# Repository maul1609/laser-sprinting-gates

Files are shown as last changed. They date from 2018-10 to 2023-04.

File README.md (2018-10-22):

# Laser Sprinting Gates

This Laser Sprinting Gate (LSG) project uses two Arduino Nanos and an Arduino Uno linked together via 
nRF24l01 modules. 

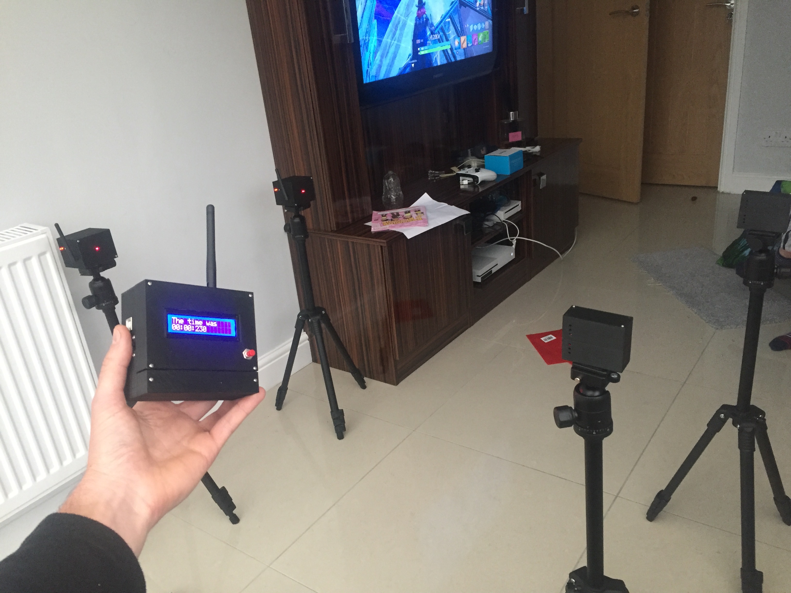
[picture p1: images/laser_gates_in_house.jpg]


<em>The Laser Speed Gates - Indoors.</em>

# Table of contents
1. [Overview](#overview)
2. [Remote control](#rem-cont)
3. [Detectors](#detectors)
4. [Dependencies](#Dependencies)
5. [Folder structure](#Folder-Structure)
6. [Contributing](#Contributing)
7. [Code of Conduct](#Code-of-Conduct)

## Overview 

The electronics fits in their own project boxes, which are 3-d printed.

There are two boxes for the laser diodes, two for the detectors / transceivers; and one for the remote control.

You set up the tripods, point the lasers into the detectors a measured distance apart and switch everything on.

Then press the pushbutton on the remote control. The LCD will say "Ready" if the laser gates are closed, or will tell you to "Close gates" if the lasers are not directed on the photodiodes.

When you run through both gates the remote control will display your time on the LCD in <b>min:sec:ms</b> format.

## Remote Control 
The remote control is operated as a "master" to two "slaves" (the detectors). When the reset button is pressed a signal is sent to the two slaves, which send a return packet using the AckPayload protocol. The signal from the master includes the time in milli-seconds when the signal is sent (which is the reference time).

The information in the return packet includes information on whether the gates are closed (i.e. laser pointing at the photodiode); the reference time; and the time at which the gate was first opened (laser beam broken) after the reset signal. If both gates have been opened the difference between these two times is the time taken. This time is then printed to the remote control LCD.

The LCD uses the LiquidCrystal library and the following code to interface to it:

<code>
LiquidCrystal lcd(1,0,5,4,3,2);
</code>

However, this may change so that the master uses pin 2 or 3 for the reset button (as an interupt can then be attached).

The remote control enclosure is 3-D printed (designs are part of this repository).

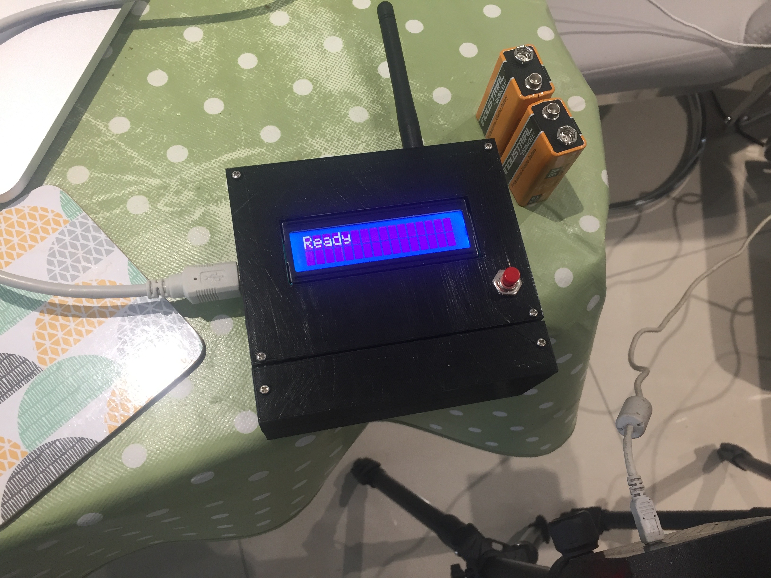
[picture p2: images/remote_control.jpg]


<em>The remote control consists of an Arduino Uno; nRF24L01 transceiver module; reset button; and LCD screen.</em>

Upload the master.ino to the arduino UNO.

## Detectors 
The detectors both use an Arduino Nano; nRF24L01 modules. The pins used on the Nano (same for the Uno board used in the remote control) are:

<table style="width:100%">
  <tr> 
    <td>
    Arduino Pin <br>
    </td>
    <td>
    nRF24L01 Pin
    </td>
  </tr>
  <tr> 
    <td>
    3.3V <br>
    </td>
    <td>
    VCC
    </td>
  </tr>
  <tr> 
    <td>
    GND <br>
    </td>
    <td>
    GND
    </td>
  </tr>
  <tr> 
    <td>
    8 <br>
    </td>
    <td>
    CSN
    </td>
  </tr>
  <tr> 
    <td>
    7 <br>
    </td>
    <td>
    CE
    </td>
  </tr>
  <tr> 
    <td>
    13 <br>
    </td>
    <td>
    SCK
    </td>
  </tr>
  <tr> 
    <td>
    11 <br>
    </td>
    <td>
    MOSI
    </td>
  </tr>
  <tr> 
    <td>
    12 <br>
    </td>
    <td>
    MISO
    </td>
  </tr>
</table>

There is also an interface to a photodiode circuit (a photodiode, two resistors and a p-type transistor), which goes to pin 2.

The photodiode circuit used is taken from Figure 3, using circuit A, with RBE=1 kohm, RL=10 kohm and a BD140 (p-type) transistor [see here](reference/Photodiode_circuit.pdf).

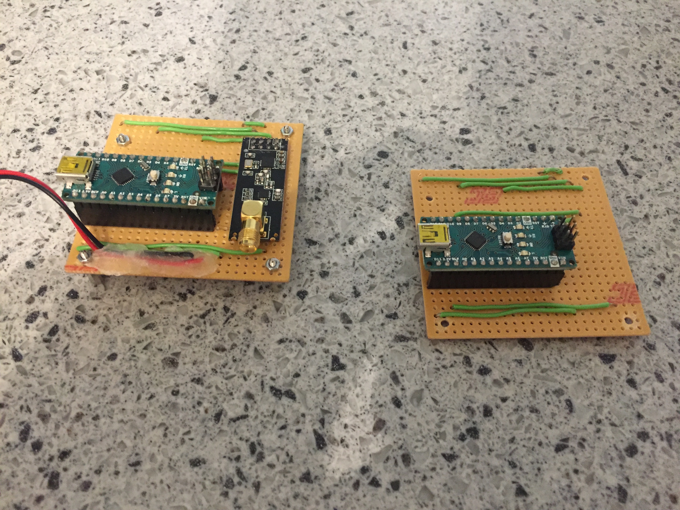
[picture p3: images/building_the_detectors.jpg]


<em>Two detector boards being constructed.</em>

Upload the slaves.ino to the Arduino Nanos: one should have 

<code>thisSlaveAddress set to RxAAA</code> 

and the other

<code>thisSlaveAddress set to RxAAB</code> 

(change the address on approximate line 12 / 13 or the slaves.ino file).

## Dependencies 

I needed to install two libraries for the Arduino for communication. The libraries are nRF24L01 and RF24.

## Folder structure 

The repository structure is now discussed

### Directory layout

    .                           
    ├── arduino               # code for the Arduino
    ├── images                # image files for the project
    ├── links                 # some links that I used 
    ├── openSCAD              # Design files in openSCAD
    ├── README.md             # This readme
    └── reference			  # contains reference documents
    
----------

**REQUIRED PARTS**

In order to **make your own Laser Sprinting Gates**, you may use the **part list below** to acquire all the components **on your own**.

<table style="width:100%">
  <tr>
    <td>
    Arduino Uno <br>
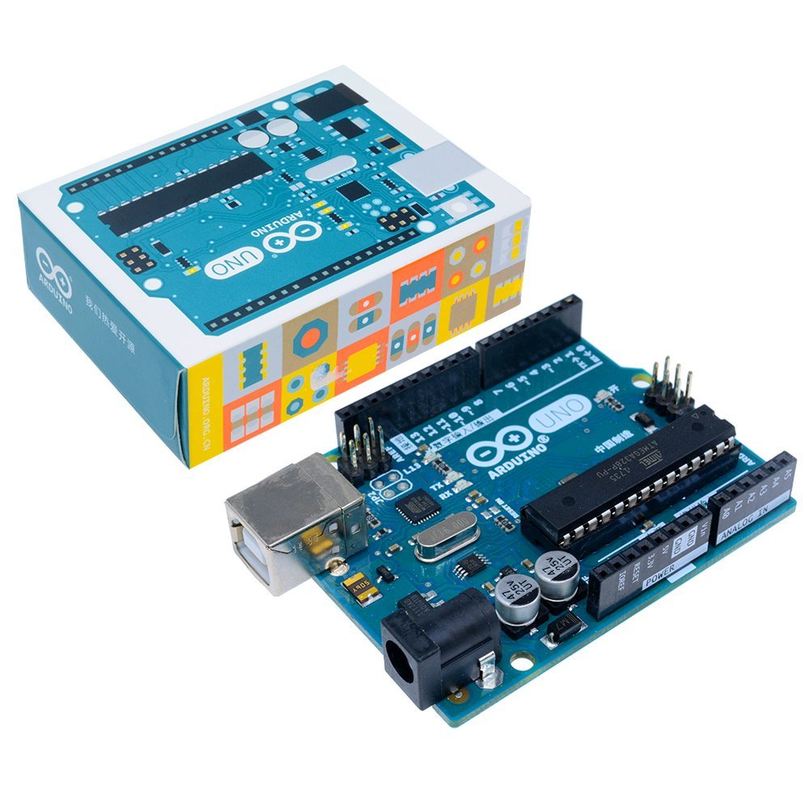
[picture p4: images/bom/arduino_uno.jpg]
    </td>
    <td><a href="https://www.amazon.co.uk/Arduino-ATMega16U2-ATMEGA328P-Microcontroller-Official/dp/B077JMX1NP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" target="_blank"> Amazon </a></td> 
    <td>£20</td>
  </tr>

  <tr>
    <td>
    Arduino Nano A000005 Board V3 x2<br>
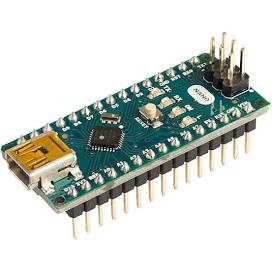
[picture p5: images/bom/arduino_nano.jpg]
    </td>
    <td><a href="https://www.rapidonline.com/arduino-nano-a000005-board-v3-73-4448" target="_blank"> Rapid Electronics </a></td> 
    <td>£15.60 x 2 = £31.20</td>
  </tr>

  <tr>
    <td>
    Strip board <br>
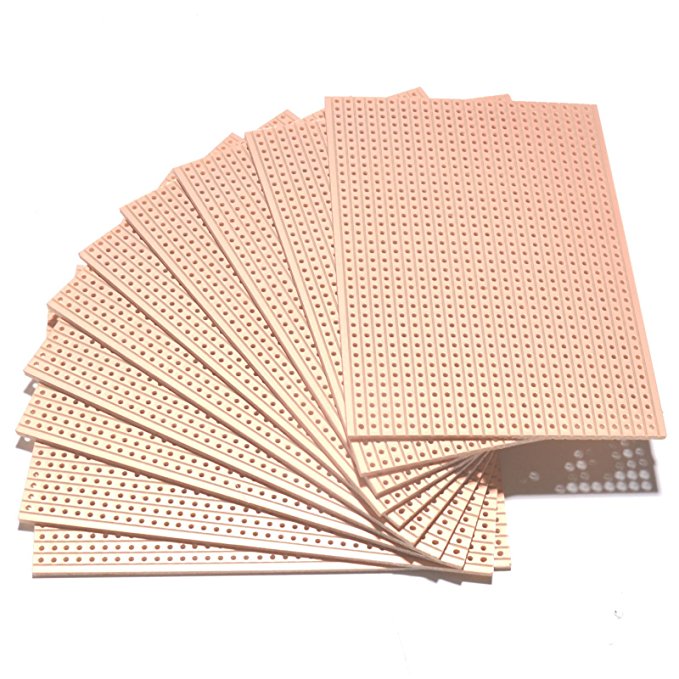
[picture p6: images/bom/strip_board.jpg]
    </td>
    <td><a href="https://www.amazon.co.uk/gp/product/B072PS947V/ref=oh_aui_detailpage_o09_s00?ie=UTF8&psc=1" target="_blank"> Amazon </a></td> 
    <td>£10</td>
  </tr>

  <tr>
    <td>
    Slide switch <br>
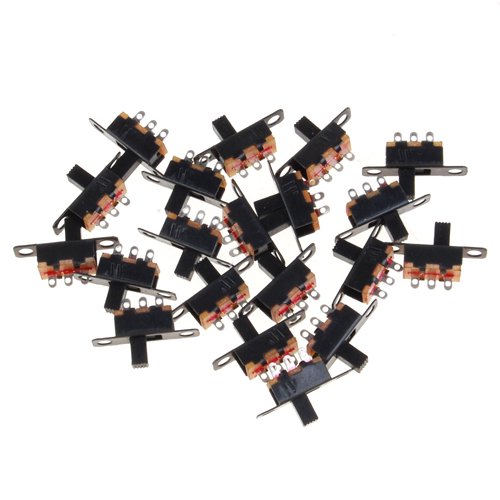
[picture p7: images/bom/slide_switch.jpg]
    </td>
    <td><a href="https://www.amazon.co.uk/gp/product/B008R50AA0/ref=oh_aui_detailpage_o07_s00?ie=UTF8&psc=1" target="_blank"> Amazon </a></td> 
    <td>£0.15</td>
  </tr>
  
  <tr>
    <td>
    PCB Header Connectors <br>
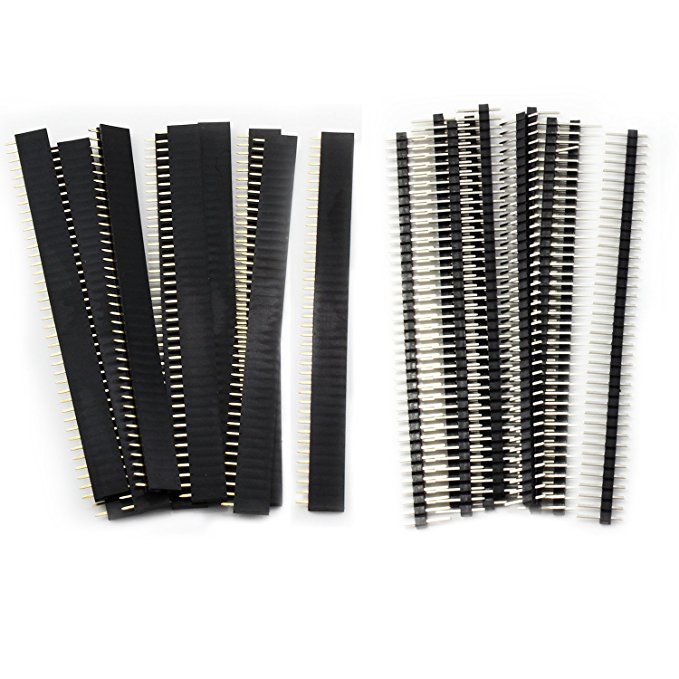
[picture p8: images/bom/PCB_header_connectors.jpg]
    </td>
    <td><a href="https://www.amazon.co.uk/gp/product/B01M69EA9O/ref=oh_aui_detailpage_o03_s00?ie=UTF8&psc=1" target="_blank"> Amazon </a></td> 
    <td>£5</td>
  </tr>

  <tr>
    <td>
    Affix Pozi Pan Head Stainless Steel Screws M2.5 12mm  <br>
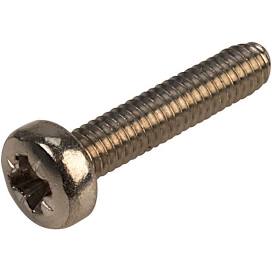
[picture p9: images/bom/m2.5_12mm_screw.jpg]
    </td>
    <td><a href="https://www.rapidonline.com/Affix-Pozi-Pan-Head-Stainless-Steel-Screws-M2-5-12mm-Pack-Of-100-33-4205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" target="_blank"> Rapid online </a></td> 
    <td>£3.40</td>
  </tr>
  
  <tr>
    <td>
    Affix Stainless Steel Plain Washers M2.5  <br>
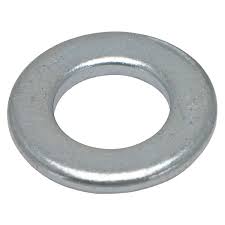
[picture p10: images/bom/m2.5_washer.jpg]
    </td>
    <td><a href="https://www.rapidonline.com/affix-stainless-steel-plain-washers-m2-5-pack-of-100-33-4315" target="_blank"> Rapid online </a></td> 
    <td>£1</td>
  </tr>
  
  <tr>
    <td>
    M2.5 nuts <br>
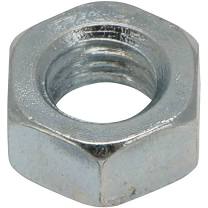
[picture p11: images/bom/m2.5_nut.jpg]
    </td>
    <td><a href="https://www.rapidonline.com/tr-fastenings-w-m2-5-hfst-tc1-steel-full-nuts-metric-m2-5-box-of-100-33-6589" target="_blank"> Rapid online </a></td> 
    <td>£1.20</td>
  </tr>

  <tr>
    <td>
    10 Metres 4mm Brown Sleeving On A Roll. <br>
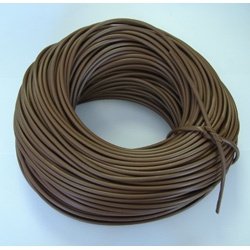
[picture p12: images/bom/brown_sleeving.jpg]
    </td>
    <td><a href="https://www.amazon.co.uk/gp/product/B006I1K7NU/ref=oh_aui_search_detailpage?ie=UTF8&psc=1" target="_blank"> Amazon </a></td> 
    <td>£2.99</td>
  </tr>
  
  <tr>
    <td>
    LED <br>
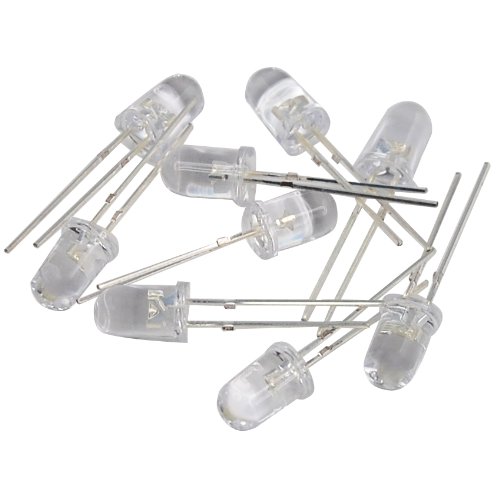
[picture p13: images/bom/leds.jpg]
    </td>
    <td><a href="https://www.amazon.co.uk/dp/B00CM5DEZO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" target="_blank"> Amazon </a></td> 
    <td>£0.65</td>
  </tr>

  <tr>
    <td>
    Linear regulator <br>
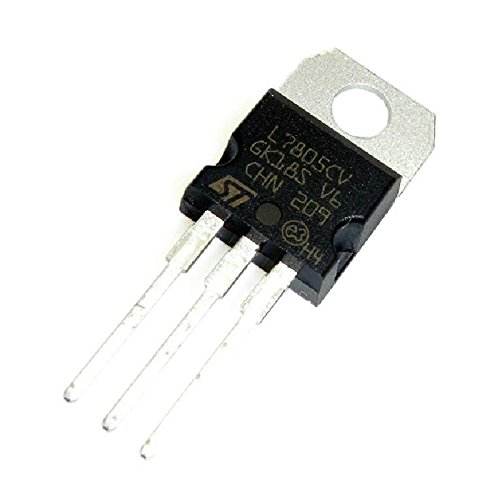
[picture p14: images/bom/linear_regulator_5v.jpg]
    </td>
    <td><a href="https://www.amazon.co.uk/LM338T-Adjustable-Positive-Voltage-Regulator/dp/B07F2YMXTR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" target="_blank"> Amazon </a></td> 
    <td>£3</td>
  </tr>

  <tr>
    <td>
    nRF24L01 module <br>
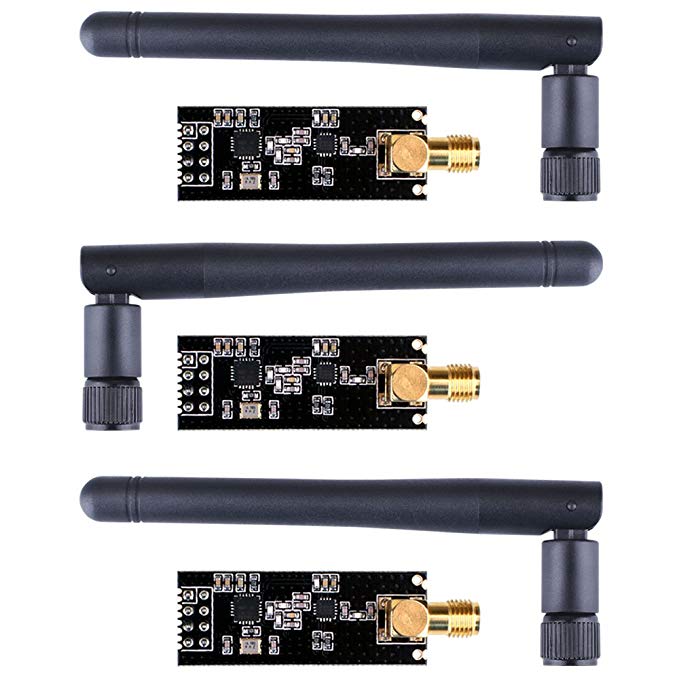
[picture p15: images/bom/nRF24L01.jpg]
    </td>
    <td><a href="https://www.amazon.co.uk/gp/product/B06WD17WLS/ref=oh_aui_detailpage_o08_s00?ie=UTF8&psc=1"> Amazon </a></td> 
    <td>£13.99</td>
  </tr>

  <tr>
    <td>
    photodiodes <br>
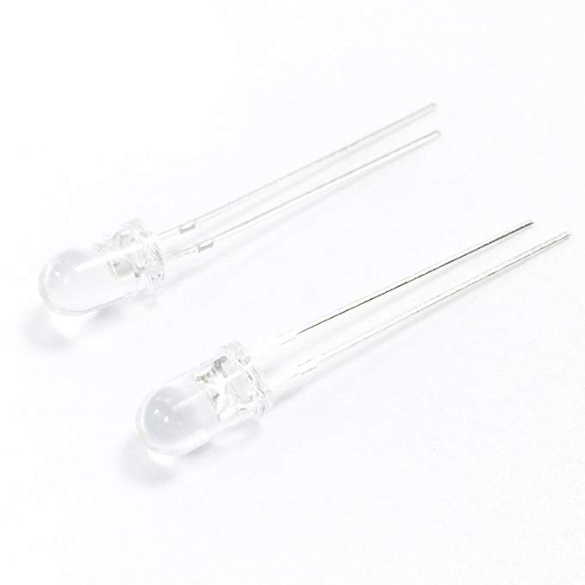
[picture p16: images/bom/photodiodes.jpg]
    </td>
    <td><a href="https://www.amazon.co.uk/gp/product/B00M1PMHO4/ref=oh_aui_detailpage_o08_s01?ie=UTF8&psc=1"> Amazon </a></td> 
    <td>£2.99</td>
  </tr>
  
  <tr>
    <td>
    Laser diodes <br>
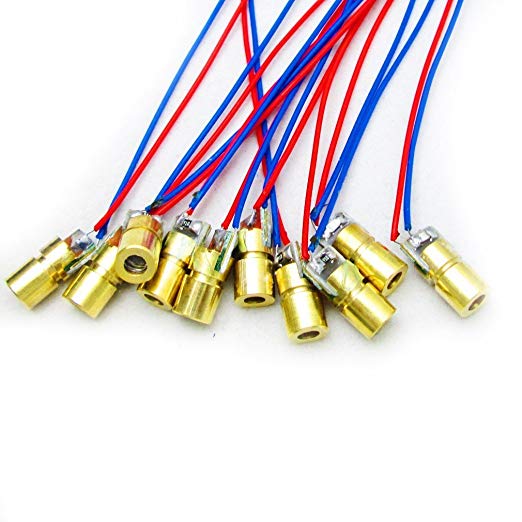
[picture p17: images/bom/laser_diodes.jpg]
    </td>
    <td><a href="https://www.amazon.co.uk/gp/product/B0798PXGTS/ref=oh_aui_detailpage_o08_s02?ie=UTF8&psc=1"> Amazon </a></td> 
    <td>£3.99</td>
  </tr>

  <tr>
    <td>
    LCD <br>
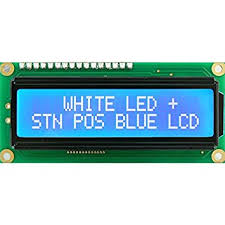
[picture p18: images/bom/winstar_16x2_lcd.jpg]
    </td>
    <td><a href="https://www.rapidonline.com/winstar-wh1602b-tmi-jt-16x2-lcd-display-blue-negative-mode-white-led-backlight-57-2228"> Rapid electronics </a></td> 
    <td>£6.40</td>
  </tr>

  <tr>
    <td>
    Pushbutton switch <br>
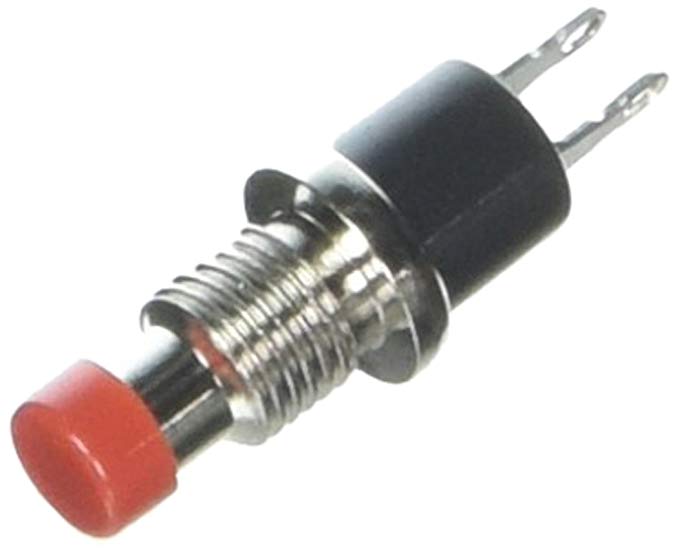
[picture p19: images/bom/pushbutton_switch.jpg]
    </td>
    <td><a href="https://www.amazon.co.uk/gp/product/B00KHV7QFE/ref=oh_aui_detailpage_o01_s00?ie=UTF8&psc=1" target="_blank"> Amazon </a></td> 
    <td>£2.22</td>
  </tr>
	
  <tr>
    <td>
    9V battery clip connector <br>
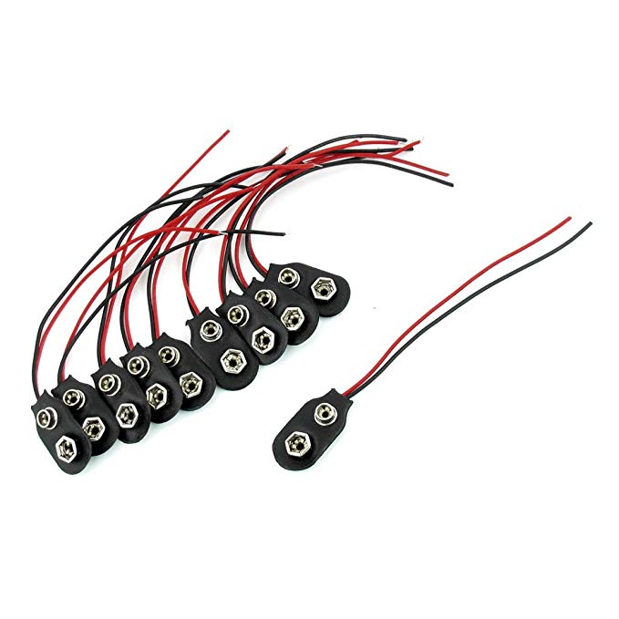
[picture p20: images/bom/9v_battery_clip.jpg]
    </td>
    <td><a href="https://www.amazon.co.uk/gp/product/B00HG8BJWM/ref=oh_aui_search_detailpage?ie=UTF8&psc=1" target="_blank"> Amazon </a></td> 
    <td>£0.87</td>
  </tr>
	
  <tr>
    <td>
    M2x50mm screws (cut to size) <br>
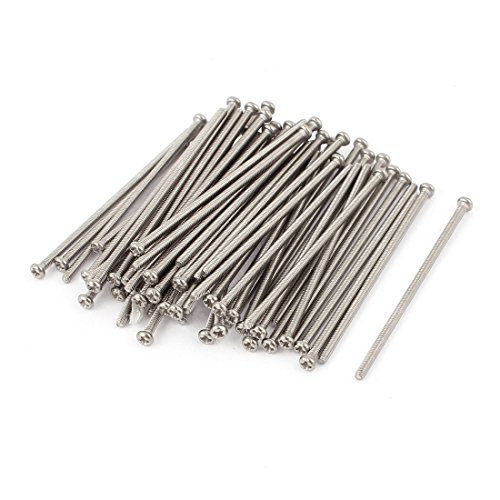
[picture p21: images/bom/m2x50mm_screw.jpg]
    </td>
    <td><a href="https://www.amazon.co.uk/Stainless-Steel-Phillips-Round-Screws/dp/B01EZZFBDG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" target="_blank"> Amazon </a></td> 
    <td>£14.35</td>
  </tr>
	
  <tr>
    <td>
    Tripod Socket <br>
    </td>
    <td><a href="https://www.amazon.co.uk/Hillman-Group-2511-4-20-13-Pack/dp/B00HYLZ33W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"> Amazon </a></td> 
    <td>£10</td>
  </tr>
	
  <tr>
    <td>
    m2 counter sunk <br>
    </td>
    <td><a href="https://www.ettinger.de/en/product/0112138"> Ettinger or similar supplier </a></td> 
    <td>£3</td>
  </tr>
	
  <tr>
    <td>
    Hex Standoff Male/Female BSB-2010E, 10mm, M2 x M2 <br>
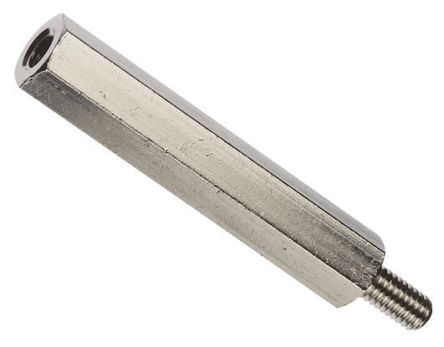
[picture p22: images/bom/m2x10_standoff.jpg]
    </td>
    <td><a href="https://uk.rs-online.com/web/p/standoffs/6643035/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"> RS </a></td> 
    <td>£7</td>
  </tr>

  <tr>
    <td>
    Hexagon Nut D934 M2 <br>
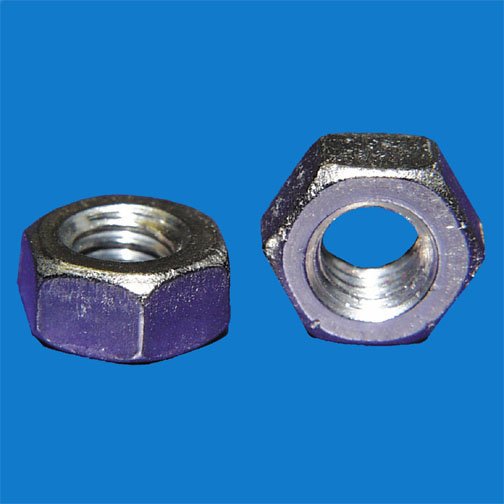
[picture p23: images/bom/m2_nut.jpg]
    </td>
    <td><a href="https://www.ettinger.de/en/product/0210011"> Ettinger or similar supplier </a></td> 
    <td>£2</td>
  </tr>
	
  <tr>
    <td>
    BD140 <br>
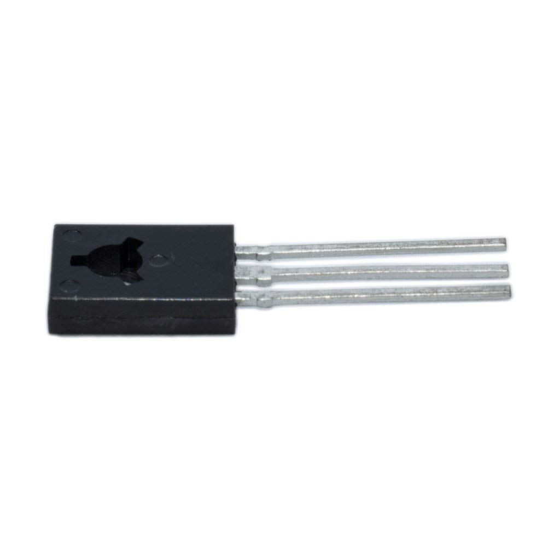
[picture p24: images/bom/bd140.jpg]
    </td>
    <td><a href="https://www.amazon.co.uk/BD140-10-CDI-Transistor-Bipolar-1-5A-TO126/dp/B07HR3BWLZ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"> Amazon </a></td> 
    <td>£3.50</td>
  </tr>

</table>

Plus: 
<ul>
<li> Resistors: 1k &Omega; ;2x220 &Omega; ;10 k &Omega;
<li> some other wire 22awg for low current connections;  
<li> Heat shrink for 22awg wire.
<li> 4 x 9V batteries
<li> 4x tripod stands. Good quality is obviously better, but you can get them quite cheap of ebay see <a href="https://www.ebay.co.uk/itm/Stretchable-Camera-Tripod-Stand-Mount-Holder-for-iPhone-8-7-Plus-Samsung-Phone/362434198720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"> here </a>
<li> 3-d printing materials:
	<ul>
	<li> PLA plastic
	</ul>
</ul>

## Contributing

Contributions to this Laser Sprinting Gate project are more than welcome. I am sure there are many improvements that could be made. I am very happy to discuss ideas for improvement and how to add/remove features.  

Please use the issue tracker at https://github.com/maul1609/laser-sprinting-gates/issues if you want to notify me of an issue or need support. If you want to contribute, please either create an issue or make a pull request. Alternatively, come and see me in Manchester and/or lets meet for a coffee and a chat!

## Code of Conduct

To be arranged.

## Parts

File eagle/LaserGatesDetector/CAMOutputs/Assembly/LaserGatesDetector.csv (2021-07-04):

Qty | Value | Device | Package | Parts | Description | PROD_ID | VALUE
1 | 0.1uF | 0.1UF-KIT-EZ-50V-20% | CAP-PTH-SMALL-KIT | C1 | 0.1µF ceramic capacitors | CAP-08370 | 0.1uF
1 | 100 | 100OHM-HORIZ-1/4W-1% | AXIAL-0.3 | R3 | 100Ω resistor | RES-12181 | 100
1 | 10K | 1MOHM-HORIZ-1/4W-5% | AXIAL-0.3 | R2 | 1MΩ resistor | RES-09329 | 1M
1 | 1K | 1MOHM-HORIZ-1/4W-5% | AXIAL-0.3 | R1 | 1MΩ resistor | RES-09329 | 1M
2 | 1k | 1KOHM-HORIZ-1/4W-1% | AXIAL-0.3 | R4, R5 | 1kΩ resistor | RES-12182 | 1k
1 | 1mF | 1000UF-RADIAL-5MM-25V-20% | CPOL-RADIAL-5MM-10MM | C3 | 1,000µF/1mF ceramic capacitors | CAP-09538 | 1mF
1 | 1uF | 10UF-POLAR-RADIAL-2.5MM-25V-20% | CPOL-RADIAL-2.5MM-5MM | C2 | 10.0µF polarized capacitors | CAP-08440 | 10uF
1 | BD140 | BD140 | TO126AV | Q1 | PNP TRANSISTOR
1 | NANO_FOOTPRINT | NANO_FOOTPRINT | NANO | J1 | Generic Nano Footprint
1 | NRF24L01 | NRF24L01 | NRF24L01 | U$1 | nrF54L01 2.4GHz with 100 Channels Emitter/Reveiver SPI Controlled
1 | PHOTOTRANSISTOR-SFH309 | PHOTOTRANSISTOR-SFH309 | SFH | U$2
1 | RED | LED5MM-KIT | LED_5MM-KIT | D1 | LED (Generic)
1 | SLIDE-SWITCH-CONRAD708070 | SLIDE-SWITCH-CONRAD708070 | SLIDE-SWITCH-CONRAD708070 | U$3
1 | VCC_1 | CONN_02 | 1X02 | J2 | Multi connection point. Often used as Generic Header-pin footprint for 0.1 inch spaced/style header connections
1 | V_REG_338T | V_REG_317SINK | TO220-ADJ | U1 | Voltage Regulator

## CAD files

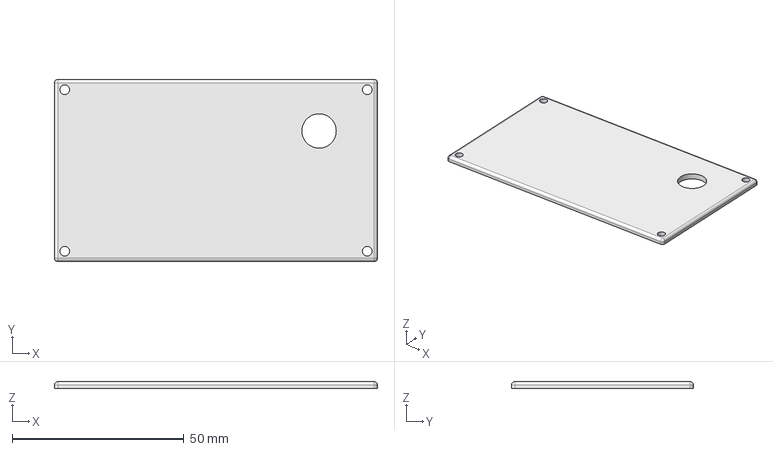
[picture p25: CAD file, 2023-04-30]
FreeCAD/receiver_lid.FCStd
94.0 x 53.0 x 2.00 mm

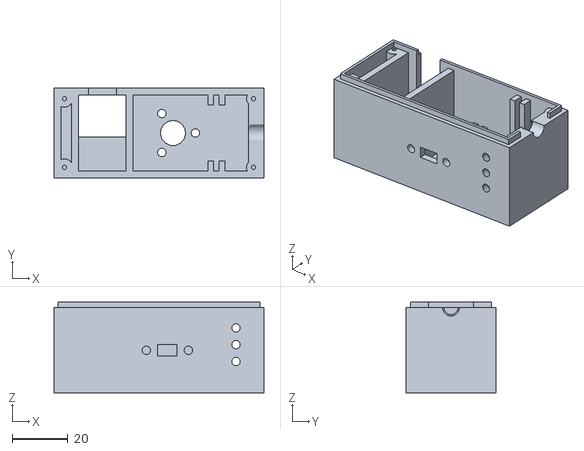
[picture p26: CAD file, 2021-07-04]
openSCAD/laser_box_bottom.stl
75.0 x 32.0 x 32.5

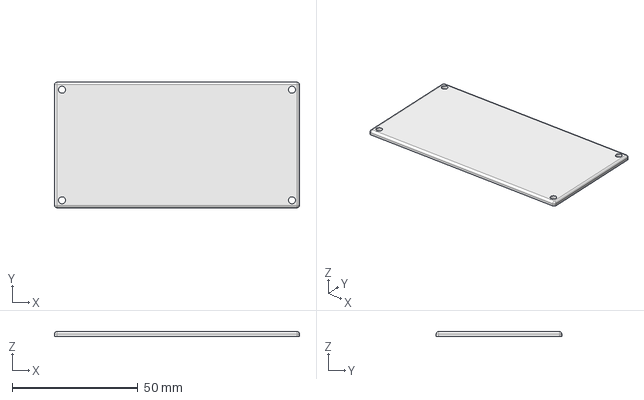
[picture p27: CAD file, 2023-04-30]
FreeCAD/remote_lid.FCStd
97.5 x 50.0 x 2.00 mm

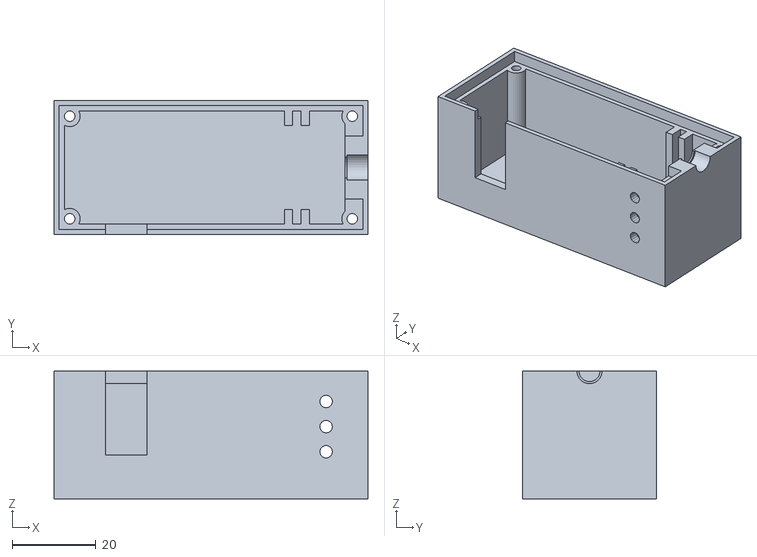
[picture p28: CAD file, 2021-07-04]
openSCAD/laser_box_top.stl
75.0 x 32.0 x 30.5

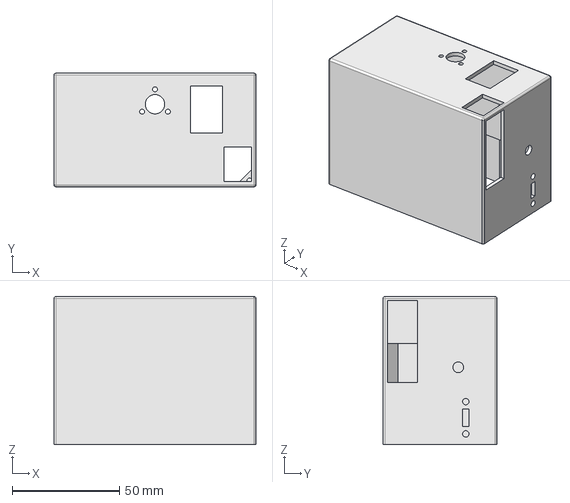
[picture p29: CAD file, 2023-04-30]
FreeCAD/receiver_box.FCStd
94.0 x 53.0 x 69.0 mm

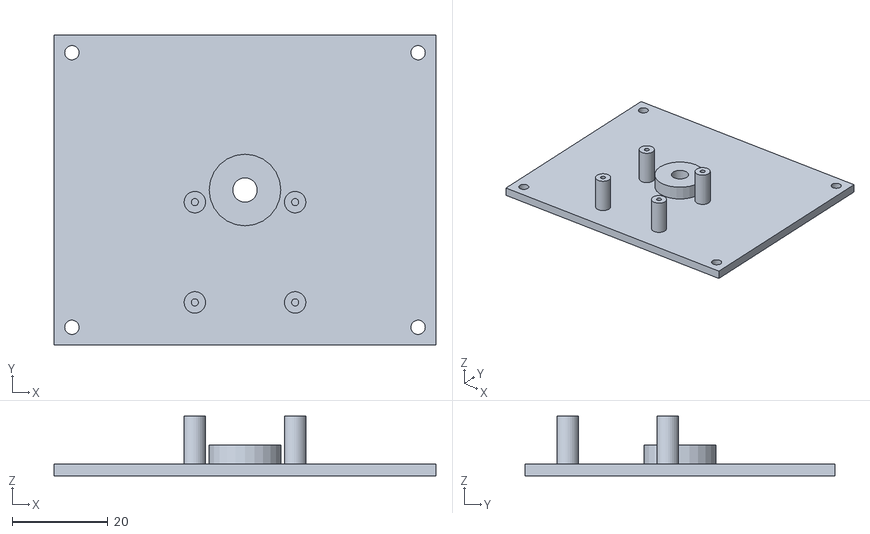
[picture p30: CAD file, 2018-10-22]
openSCAD/detector_cover.stl
80.0 x 65.0 x 12.5

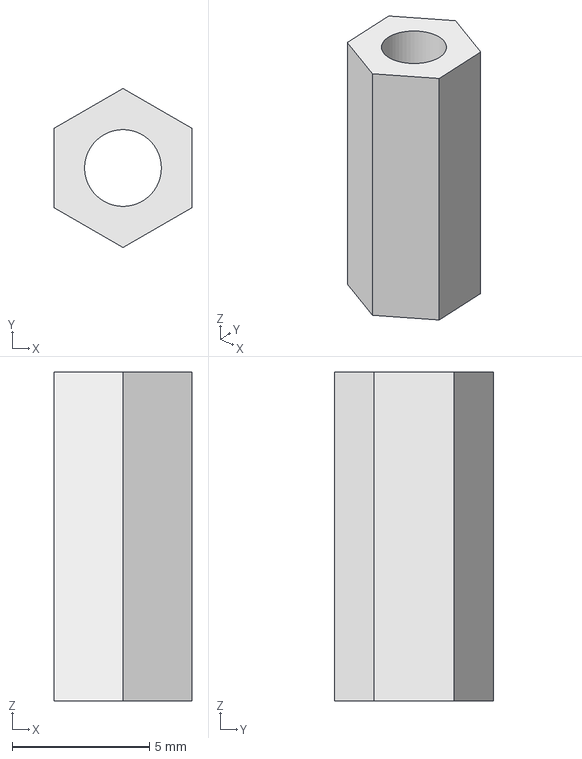
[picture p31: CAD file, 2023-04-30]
FreeCAD/LCD_spacer.FCStd
5.02 x 5.80 x 12.0 mm

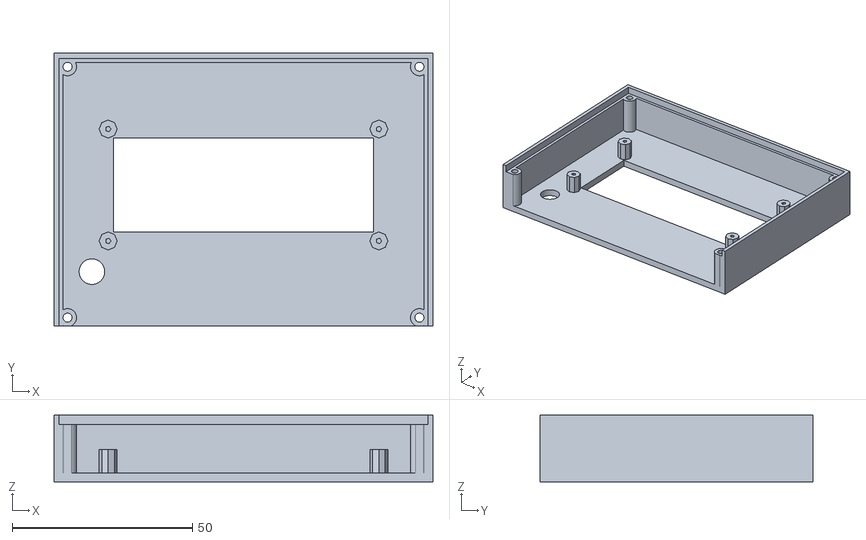
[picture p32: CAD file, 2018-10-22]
openSCAD/remote_controller_top_LCD_TOP.stl
105.0 x 75.5 x 18.5

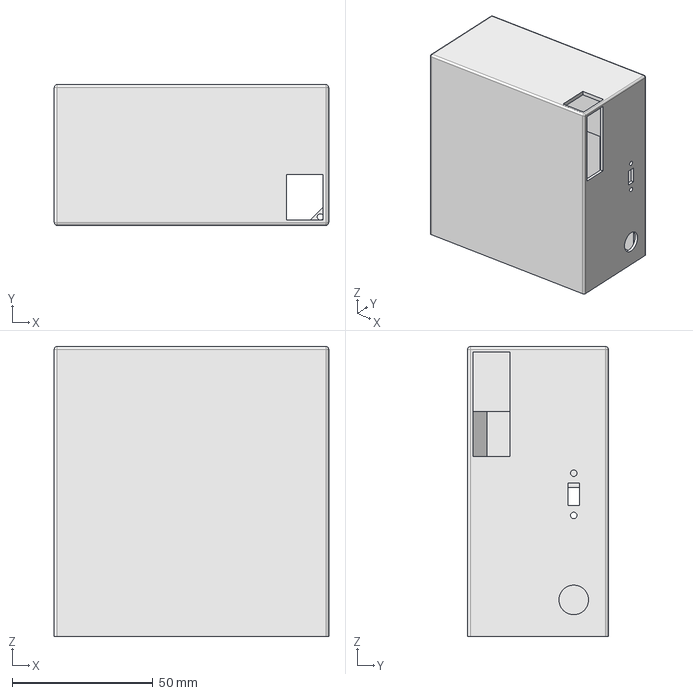
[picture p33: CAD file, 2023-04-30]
FreeCAD/remote_box.FCStd
97.5 x 50.0 x 103.0 mm

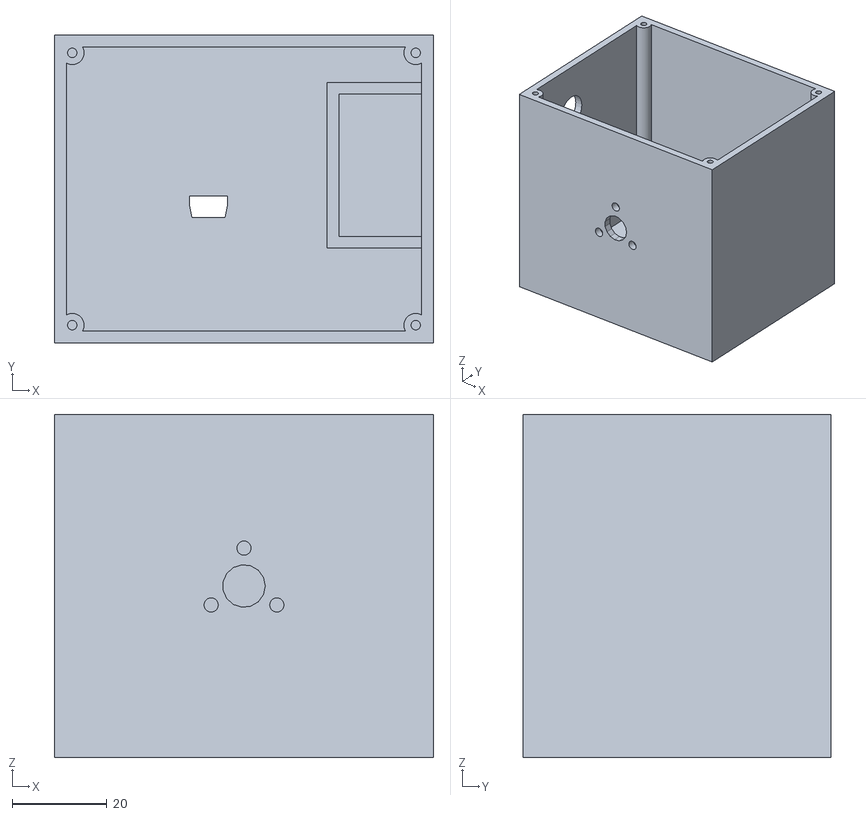
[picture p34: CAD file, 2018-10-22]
openSCAD/detector.stl
80.0 x 65.0 x 72.5

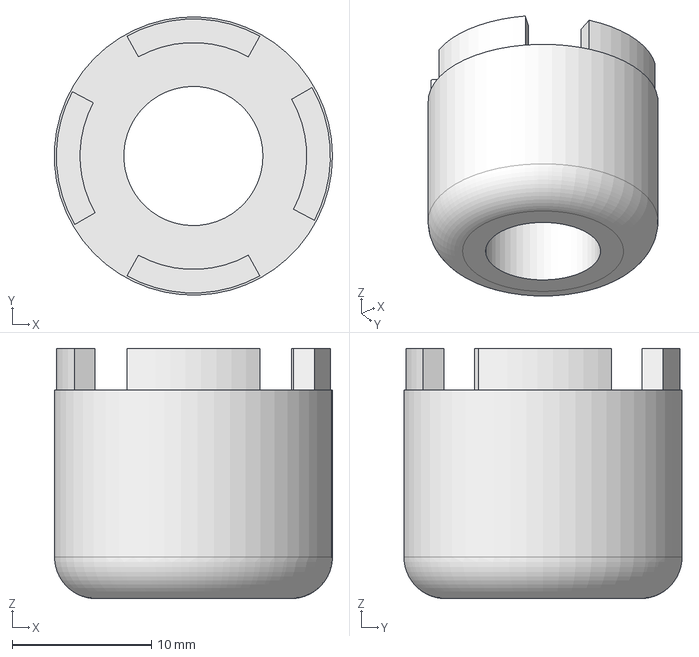
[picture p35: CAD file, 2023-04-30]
FreeCAD/remote_eye.FCStd
20.0 x 20.0 x 18.0 mm

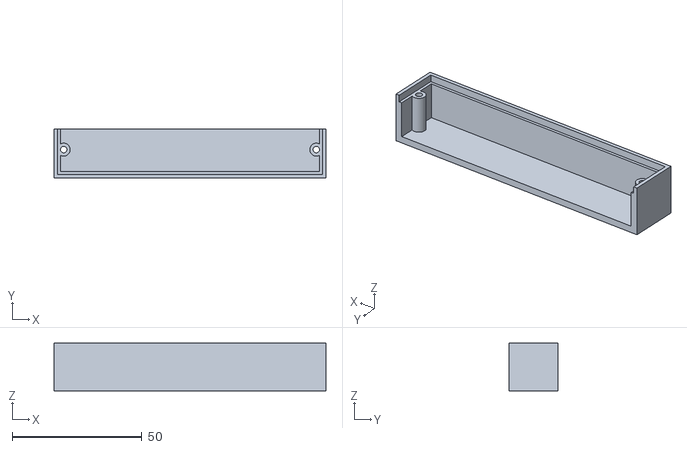
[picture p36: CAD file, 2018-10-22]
openSCAD/remote_controller_top_LCD_BOTTOM.stl
105.0 x 19.0 x 18.5

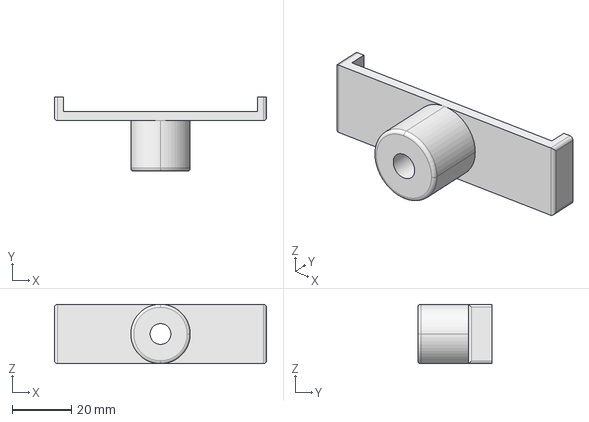
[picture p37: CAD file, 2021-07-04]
FreeCAD/sun_shield.FCStd
71.3 x 25.0 x 20.0 mm

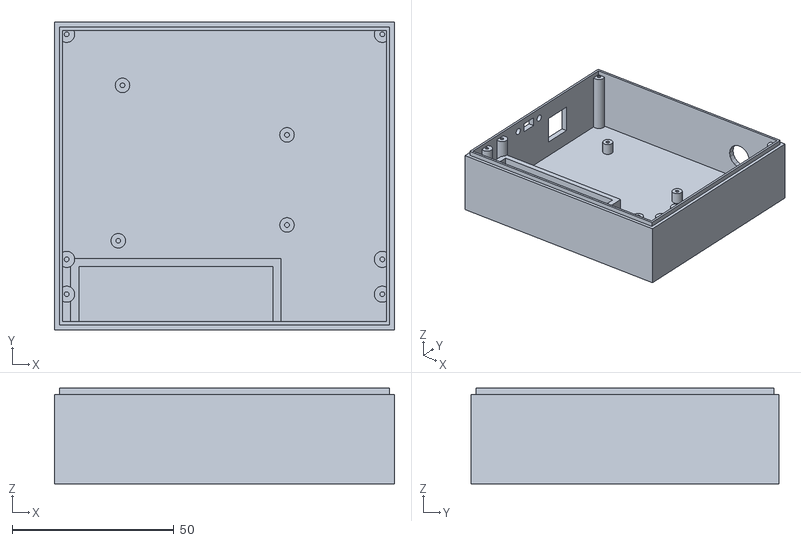
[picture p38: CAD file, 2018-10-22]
openSCAD/remote_controller_bottom.stl
105.0 x 95.0 x 29.5

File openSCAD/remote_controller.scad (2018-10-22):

xdim=100;
ydim=90;
zdim=25;
zdim2=16;
th=2.5;

BOTTOM=1;
TOP=2;
LCD_TOP=1;
LCD_BOTTOM=2;
part=TOP;
part2=LCD_TOP;
if(part==BOTTOM) {
    difference() 
    {
        union() {
            //box
            difference() {
                cube([xdim+2*th,ydim+2*th,zdim+th],true);
                translate([0,0,th/2+0.01]) cube([xdim,ydim,zdim],true);
            }
            // screw hole/mounts
            translate([0,-th/2+17/2,0]) {
                translate([-(xdim/2-th/2),-(ydim/2-th/2),th/2]) {
                    cylinder(h=zdim,d=5,$fn=30,center=true);
                }
                translate([(xdim/2-th/2),-(ydim/2-th/2),th/2]) {
                    cylinder(h=zdim,d=5,$fn=30,center=true);
                }
            }
            
            translate([-(xdim/2-th/2),(ydim/2-th/2),th/2]) {
                cylinder(h=zdim,d=5,$fn=30,center=true);
            }
            translate([(xdim/2-th/2),(ydim/2-th/2),th/2]) {
                cylinder(h=zdim,d=5,$fn=30,center=true);
            }
            translate([0,18,0]) {
                translate([-(xdim/2-th/2),-(ydim/2-th/2),th/2]) {
                    cylinder(h=zdim,d=5,$fn=30,center=true);
                }
                translate([(xdim/2-th/2),-(ydim/2-th/2),th/2]) {
                    cylinder(h=zdim,d=5,$fn=30,center=true);
                }
            }
            // arduino mounts
            translate([-(xdim/2)+21-th,(ydim/2)-17,-(zdim/2)+5/2+th/2]) {
                cylinder(h=5,d=4.5,$fn=30,center=true);
            }
            translate([-(xdim/2)+21-th-1.3,(ydim/2)-17-48,-(zdim/2)+5/2+th/2]) {
                cylinder(h=5,d=4.5,$fn=30,center=true);
            }
            translate([-(xdim/2)+21-th+64.4-13.6,(ydim/2)-17-15.3,-(zdim/2)+5/2+th/2]) {
                cylinder(h=5,d=4.5,$fn=30,center=true);
            }
            translate([-(xdim/2)+21-th+64.4-13.6,(ydim/2)-17-(44.12-1),-(zdim/2)+5/2+th/2]) {
                cylinder(h=5,d=4.5,$fn=30,center=true);
            }

            
            
            
            // slot
            difference() {
                translate([0,0,zdim/2+th/2-1.5+3-1]) cube([xdim+2,ydim+2,3],true);
                translate([0,0,zdim/2+th/2-1.5+3-1]) cube([xdim,ydim,3.1],true);
            }                
        }
        

        // screw hole/mounts
        translate([0,-th/2+17/2,0]) {
            translate([-(xdim/2-th/2),-(ydim/2-th/2),th/2]) {
                cylinder(h=zdim,d=1.5,$fn=30,center=true);
            }
            translate([(xdim/2-th/2),-(ydim/2-th/2),th/2]) {
                cylinder(h=zdim,d=1.5,$fn=30,center=true);
            }
        }
        translate([-(xdim/2-th/2),(ydim/2-th/2),th/2]) {
            cylinder(h=zdim,d=1.5,$fn=30,center=true);
        }
        translate([(xdim/2-th/2),(ydim/2-th/2),th/2]) {
            cylinder(h=zdim,d=1.5,$fn=30,center=true);
        }
        translate([0,18,0]) {
            translate([-(xdim/2-th/2),-(ydim/2-th/2),th/2]) {
                cylinder(h=zdim,d=1.5,$fn=30,center=true);
            }
            translate([(xdim/2-th/2),-(ydim/2-th/2),th/2]) {
                cylinder(h=zdim,d=1.5,$fn=30,center=true);
            }
        }

        // arduino mounts
        translate([-(xdim/2)+21-th,(ydim/2)-17,-(zdim/2)+5/2+th/2]) {
            cylinder(h=5,d=1.5,$fn=30,center=true);
        }
        translate([-(xdim/2)+21-th-1.3,(ydim/2)-17-48,-(zdim/2)+5/2+th/2]) {
            cylinder(h=5,d=1.5,$fn=30,center=true);
        }
        translate([-(xdim/2)+21-th+64.4-13.6,(ydim/2)-17-15.3,-(zdim/2)+5/2+th/2]) {
            cylinder(h=5,d=1.5,$fn=30,center=true);
        }
        translate([-(xdim/2)+21-th+64.4-13.6,(ydim/2)-17-(44.12-1),-(zdim/2)+5/2+th/2]) {
            cylinder(h=5,d=1.5,$fn=30,center=true);
        }

        // usb
        translate([-(xdim/2),(ydim/2)-17-12.5,-(zdim/2)+th/2+12/2+7]) cube([10,13,12],true);

        // aerial
        translate([21-th-(xdim/2)+74-13.6-1,(ydim/2),-1]) rotate([90,0,0]) cylinder(h=10,d=11,center=true);
        
        // switch
        translate([-xdim/2,-5,11]) rotate([90,0,0]) switch();
        

    }
    
    translate([-15,-(ydim/2)+17./2,-(zdim/2)+th/2+15/2]) battery_holder();
} else if(part==TOP) {
    difference() 
    {
        union() {
            //box
            difference() {
                cube([xdim+2*th,ydim+2*th,zdim2+th],true);
                translate([0,0,th/2+0.01]) cube([xdim,ydim,zdim2],true);
            }
            // screw hole/mounts
            translate([0,-th/2+17/2,0]) {
                translate([-(xdim/2-th/2),-(ydim/2-th/2),th/2]) {
                    cylinder(h=zdim2,d=5,$fn=30,center=true);
                }
                translate([(xdim/2-th/2),-(ydim/2-th/2),th/2]) {
                    cylinder(h=zdim2,d=5,$fn=30,center=true);
                }
            }
            
            translate([-(xdim/2-th/2),(ydim/2-th/2),th/2]) {
                cylinder(h=zdim2,d=5,$fn=30,center=true);
            }
            translate([(xdim/2-th/2),(ydim/2-th/2),th/2]) {
                cylinder(h=zdim2,d=5,$fn=30,center=true);
            }
            translate([0,18,0]) {
                translate([-(xdim/2-th/2),-(ydim/2-th/2),th/2]) {
                    cylinder(h=zdim2,d=5,$fn=30,center=true);
                }
                translate([(xdim/2-th/2),-(ydim/2-th/2),th/2]) {
                    cylinder(h=zdim2,d=5,$fn=30,center=true);
                }
            }
            
            
            // mounts for LCD
            
            // hole for LCD
            translate([0,(ydim/2)-34,-zdim2/2+(9-th)/2+th/2]) {
                translate([75/2,31/2,0]) cylinder(d=5,h=9-th,center=true);
                translate([-75/2,31/2,0]) cylinder(d=5,h=9-th,center=true);
                translate([75/2,-31/2,0]) cylinder(d=5,h=9-th,center=true);
                translate([-75/2,-31/2,0]) cylinder(d=5,h=9-th,center=true);
            }
            
            
        }
        // slot
        translate([0,0,zdim2/2+th/2+2.6/2-2.6]) cube([xdim+2.2,ydim+2.2,2.6],true);
        // screw hole/mounts
        translate([0,-th/2+17/2,0]) {
            translate([-(xdim/2-th/2),-(ydim/2-th/2),th/2]) {
                cylinder(h=zdim,d=2.5,$fn=30,center=true);
            }
            translate([(xdim/2-th/2),-(ydim/2-th/2),th/2]) {
                cylinder(h=zdim,d=2.5,$fn=30,center=true);
            }
        }
        translate([-(xdim/2-th/2),(ydim/2-th/2),th/2]) {
            cylinder(h=zdim,d=2.5,$fn=30,center=true);
        }
        translate([(xdim/2-th/2),(ydim/2-th/2),th/2]) {
            cylinder(h=zdim,d=2.5,$fn=30,center=true);
        }
        translate([0,18,0]) {
            translate([-(xdim/2-th/2),-(ydim/2-th/2),th/2]) {
                cylinder(h=zdim,d=2.5,$fn=30,center=true);
            }
            translate([(xdim/2-th/2),-(ydim/2-th/2),th/2]) {
                cylinder(h=zdim,d=2.5,$fn=30,center=true);
            }
        }
        
        // hole for button:
        translate([-xdim/2+8,-ydim/2+32,0]) cylinder(d=7.1,h=50,$fn=30,center=true);
        
        // hole for LCD
        translate([0,(ydim/2)-34,-zdim2/2+(20)/2+th/2]) {
            cube([72,26,100],true);
            translate([75/2,31/2,0]) cylinder(d=1.6,h=20,center=true);
            translate([-75/2,31/2,0]) cylinder(d=1.6,h=20,center=true);
            translate([75/2,-31/2,0]) cylinder(d=1.6,h=20,center=true);
            translate([-75/2,-31/2,0]) cylinder(d=1.6,h=20,center=true);
        }
        
        // split them
        //translate([0,-ydim/2+17,0]) cube([2*xdim,0.5,zdim],true);
        if(part2==LCD_TOP) {
            translate([0,-ydim/2+17-200/2,0]) cube([2*xdim,200,zdim],true);
        } else if(part2==LCD_BOTTOM) {
            translate([0,-ydim/2+17+200/2-0.5,0]) cube([2*xdim,200,zdim],true);
        }
        
    }    
}

module battery_holder() 
{
    difference() {
        cube([60+th*2,17.+th*2,15+th*2],true);
        translate([0,0,th]) cube([60,17,15+th*2],true);
    }
}


module switch() 
{
    rotate([90,0,90]) {
        translate([0,15/2,0]) cylinder(d=3,h=10,$fn=30,center=true);
        translate([0,-15/2,0]) cylinder(d=3,h=10,$fn=30,center=true);
        translate([0,0,0]) cube([4,7,10],true);
    }
}

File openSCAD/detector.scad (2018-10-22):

xdim=75;
ydim=60;
zdim=70;
th=2.5;

BOX=1;
COVER=2;
item=BOX;
item=COVER;

if (item==BOX) {
    difference() {
        union() {
            difference() {
                cube([xdim+2*th,ydim+2*th,zdim+th],true);
                translate([0,0,th/2]) cube([xdim,ydim,zdim],true);
            }
            translate([-(xdim/2-th/2),-(ydim/2-th/2),th/2]) {
                cylinder(h=zdim,d=5,$fn=30,center=true);
            }
            translate([(xdim/2-th/2),-(ydim/2-th/2),th/2]) {
                cylinder(h=zdim,d=5,$fn=30,center=true);
            }
            translate([-(xdim/2-th/2),(ydim/2-th/2),th/2]) {
                cylinder(h=zdim,d=5,$fn=30,center=true);
            }
            translate([(xdim/2-th/2),(ydim/2-th/2),th/2]) {
                cylinder(h=zdim,d=5,$fn=30,center=true);
            }
        }
        translate([-xdim/2,-ydim/2+21,0]) {
            translate([0,20,-5]) switch();
            // aerial
            translate([0,1,-zdim/2+54.5]) rotate([90,0,90]) cylinder(h=10,d=11,$fn=30,center=true);
            // LED
            translate([0,20,-25]) rotate([90,0,90]) cylinder(h=10,d=5.1,$fn=30,center=true);
        }

        // USB
        translate([-xdim/2+30,-ydim/2+25.5+2,-zdim/2]) usb();
        translate([0,-ydim/2,0]) tripod();

        // holes
        translate([-(xdim/2-th/2),-(ydim/2-th/2),th/2]) {
            cylinder(h=zdim,d=2,$fn=30,center=true);
        }
        translate([(xdim/2-th/2),-(ydim/2-th/2),th/2]) {
            cylinder(h=zdim,d=2,$fn=30,center=true);
        }
        translate([-(xdim/2-th/2),(ydim/2-th/2),th/2]) {
            cylinder(h=zdim,d=2,$fn=30,center=true);
        }
        translate([(xdim/2-th/2),(ydim/2-th/2),th/2]) {
            cylinder(h=zdim,d=2,$fn=30,center=true);
        }
        
    }

    translate([xdim/2-17.5/2,ydim/2-30/2-10,-zdim/2+20+th/2]) battery_holder();
} else if(item==COVER) {
    rotate([180,0,0]) {
        difference() {
            union() {
                difference() {
                    cube([xdim+2*th,ydim+2*th,th],true);
                    // screw holes
                    translate([-(xdim/2-th/2),-(ydim/2-th/2),th/2]) {
                        cylinder(h=zdim,d=3,$fn=30,center=true);
                    }
                    translate([(xdim/2-th/2),-(ydim/2-th/2),th/2]) {
                        cylinder(h=zdim,d=3,$fn=30,center=true);
                    }
                    translate([-(xdim/2-th/2),(ydim/2-th/2),th/2]) {
                        cylinder(h=zdim,d=3,$fn=30,center=true);
                    }
                    translate([(xdim/2-th/2),(ydim/2-th/2),th/2]) {
                        cylinder(h=zdim,d=3,$fn=30,center=true);
                    }
                    
                    
                    
                }
                // breakout board mounts
                translate([0,22.86/2+2.54,-13/2-th/2]) {
                    translate([22.86/2,22.86/2,0]) {
                        cylinder(h=13,d=4.5,$fn=30,center=true);
                    }
                    translate([22.86/2,-22.86/2,0]) {
                        cylinder(h=13,d=4.5,$fn=30,center=true);
                    }
                    translate([-22.86/2,22.86/2,0]) {
                        cylinder(h=13,d=4.5,$fn=30,center=true);
                    }
                    translate([-22.86/2,-22.86/2,0]) {
                        cylinder(h=13,d=4.5,$fn=30,center=true);
                    }
                }
                
                // photodiode pinhole
                translate([0,0,-7/2-th/2]) cylinder(d=15,h=7,center=true);
            }
            // photodiode hole
            translate([0,0,0]) {
                cylinder(h=zdim,d=5.1,$fn=30,center=true);
            }
            // breakout board mounts
            translate([0,22.86/2+2.54,-13/2-th/2]) {
                translate([22.86/2,22.86/2,0]) {
                    cylinder(h=13,d=1.7,$fn=30,center=true);
                }
                translate([22.86/2,-22.86/2,0]) {
                    cylinder(h=13,d=1.7,$fn=30,center=true);
                }
                translate([-22.86/2,22.86/2,0]) {
                    cylinder(h=13,d=1.7,$fn=30,center=true);
                }
                translate([-22.86/2,-22.86/2,0]) {
                    cylinder(h=13,d=1.7,$fn=30,center=true);
                }
            }
            
            
        }  
    }  
}

module battery_holder() 
{
    difference() {
        cube([17.5+th*2,30+th*2,40+th*2],true);
        translate([0,0,th]) cube([17.5,30,40+th*2],true);
    }
}

module switch() 
{
    rotate([90,0,90]) {
        translate([0,15/2,0]) cylinder(d=3,h=10,$fn=30,center=true);
        translate([0,-15/2,0]) cylinder(d=3,h=10,$fn=30,center=true);
        translate([0,0,0]) cube([4,7,10],true);
    }
}

module usb() 
{
    rotate([-90,0,0]) hull() {
        cube([8,10,2],true);
        translate([0,0,-2.5]) cube([7,10,2],true);
    }
}

module tripod()
{
    rotate([90,0,0]) {
        cylinder(h=10,d=9,center=true);
        translate([0,8,0]) cylinder(h=10,d=3,$fn=30,center=true);
        rotate([0,0,120]) translate([0,8,0]) cylinder(h=10,d=3,$fn=30,center=true);
        rotate([0,0,-120]) translate([0,8,0]) cylinder(h=10,d=3,$fn=30,center=true);
    }
}

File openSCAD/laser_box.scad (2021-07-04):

xdim=70;
ydim=27;
zdim=28;
th=2.5;

BOTTOM=1;
TOP=2;
part=BOTTOM;

if(part==BOTTOM) {
    difference() 
    {
        union() {
            difference() {
                cube([xdim+2*th,ydim+2*th,zdim+th],true);
                translate([0,0,th/2]) cube([xdim,ydim,zdim],true);
            }
            translate([-(xdim/2-th/2),-(ydim/2-th/2),th/2]) {
                cylinder(h=zdim,d=6,$fn=30,center=true);
            }
            translate([(xdim/2-th/2),-(ydim/2-th/2),th/2]) {
                cylinder(h=zdim,d=5,$fn=30,center=true);
            }
            translate([-(xdim/2-th/2),(ydim/2-th/2),th/2]) {
                cylinder(h=zdim,d=6,$fn=30,center=true);
            }
            translate([(xdim/2-th/2),(ydim/2-th/2),th/2]) {
                cylinder(h=zdim,d=5,$fn=30,center=true);
            }
            translate([xdim/2-0.5+0.25,0,0]) cube([5.5,ydim+2*th,zdim+th],true);
            
            translate([-8,0,0]) {
                // battery holder
                translate([-22,0,0]) cube([th,ydim+2*th,zdim+th],true);
                translate([17+th-22,0,0]) cube([th,ydim+2*th,zdim+th],true);

                // board holder
                difference() {
                    union() {
                        translate([17+th+7,0,0]) cube([2,ydim+2*th,zdim+th],true);
                        translate([17+th+7+2+2,0,0]) cube([2,ydim+2*th,zdim+th],true);
                    }
                    translate([17+th+7+2+2,0,0]) cube([20,20,zdim+th],true);
                    
                }
            }
            
            // slot
            difference() {
                translate([0,0,zdim/2+th/2-1.5+3-1]) cube([xdim+2,ydim+2,3],true);
                translate([0,0,zdim/2+th/2-1.5+3-1]) cube([xdim,ydim,3],true);
                translate([xdim/2,0,zdim/2+th/2-1.5+3-1]) cube([6,16,10],true);
            }                
        }
        
        translate([5,0,-zdim/2]) rotate([90,0,90]) tripod();

        translate([-(xdim/2-th/2),-(ydim/2-th/2),th/2]) {
            cylinder(h=zdim,d=1.5,$fn=30,center=true);
        }
        translate([(xdim/2-th/2),-(ydim/2-th/2),th/2]) {
            cylinder(h=zdim,d=1.5,$fn=30,center=true);
        }
        translate([-(xdim/2-th/2),(ydim/2-th/2),th/2]) {
            cylinder(h=zdim,d=1.5,$fn=30,center=true);
        }
        translate([(xdim/2-th/2),(ydim/2-th/2),th/2]) {
            cylinder(h=zdim,d=1.5,$fn=30,center=true);
        }

        // laser
        translate([(xdim)/2-0.5+0.5,0,(zdim+th)/2]) rotate([0,90,0]) cylinder(d=6,h=5,$fn=30,center=true);
        translate([(xdim)/2-0.5+0.5,0,(zdim+th)/2]) rotate([0,90,0]) cylinder(d=5,h=10,$fn=30,center=true);
        
        // switch
        translate([3,-ydim/2,0]) rotate([90,0,90]) switch();
        
        for (i=[1:3])
            translate([xdim/2-7.5,0,-zdim/2+10+(i-1)*6]) rotate([90,0,0]) cylinder(d=3,h=100,$fn=16,center=true); 
        
        // hole for charge point
        translate([-20.25,6,-zdim/2]) cube([17,15,10],center=true);
        // battery slot
        translate([-20.25,ydim/2,7.25]) cube([10,10,20],true);

    }
} else if(part==TOP) {
    difference() 
    {
        union() {
            difference() {
                cube([xdim+2*th,ydim+2*th,zdim+th],true);
                translate([0,0,th/2]) cube([xdim,ydim,zdim],true);
            }
            translate([-(xdim/2-th/2),-(ydim/2-th/2),th/2]) {
                cylinder(h=zdim,d=5,$fn=30,center=true);
            }
            translate([(xdim/2-th/2),-(ydim/2-th/2),th/2]) {
                cylinder(h=zdim,d=5,$fn=30,center=true);
            }
            translate([-(xdim/2-th/2),(ydim/2-th/2),th/2]) {
                cylinder(h=zdim,d=5,$fn=30,center=true);
            }
            translate([(xdim/2-th/2),(ydim/2-th/2),th/2]) {
                cylinder(h=zdim,d=5,$fn=30,center=true);
            }
            translate([xdim/2-0.5+0.25,0,0]) cube([5.5,ydim+2*th,zdim+th],true);
            
            translate([-8,0,0]) {

                // board holder
                difference() {
                    union() {
                        translate([17+th+7,0,0]) cube([2,ydim+2*th,zdim+th],true);
                        translate([17+th+7+2+2,0,0]) cube([2,ydim+2*th,zdim+th],true);
                    }
                    translate([17+th+7+2+2,0,0]) cube([20,20,zdim+th],true);
                    
                }
            }
        }
        

        translate([-(xdim/2-th/2),-(ydim/2-th/2),th/2]) {
            cylinder(h=zdim*2,d=2.5,$fn=30,center=true);
        }
        translate([(xdim/2-th/2),-(ydim/2-th/2),th/2]) {
            cylinder(h=zdim*2,d=2.5,$fn=30,center=true);
        }
        translate([-(xdim/2-th/2),(ydim/2-th/2),th/2]) {
            cylinder(h=zdim*2,d=2.5,$fn=30,center=true);
        }
        translate([(xdim/2-th/2),(ydim/2-th/2),th/2]) {
            cylinder(h=zdim*2,d=2.5,$fn=30,center=true);
        }

        // laser
        translate([(xdim)/2-0.5+0.5,0,(zdim+th)/2]) rotate([0,90,0]) cylinder(d=6,h=5,$fn=30,center=true);
        translate([(xdim)/2-0.5+0.5,0,(zdim+th)/2]) rotate([0,90,0]) cylinder(d=5,h=10,$fn=30,center=true);
        
        
        for (i=[1:3])
            translate([xdim/2-7.5,0,-zdim/2+10+(i-1)*6]) rotate([90,0,0]) cylinder(d=3,h=100,$fn=16,center=true); 
    
        // slot
        difference() {
            translate([0,0,zdim/2+th/2-1.5]) cube([xdim+2.5,ydim+2.5,3],true);
            translate([xdim/2,0,zdim/2+th/2-1.5]) cube([10,15,10],true);
        }
        // battery slot
        translate([-20.25,-ydim/2,5.25]) cube([10,10,20],true);
    }
}


module switch() 
{
    rotate([90,0,90]) {
        translate([0,15/2,0]) cylinder(d=3,h=10,$fn=30,center=true);
        translate([0,-15/2,0]) cylinder(d=3,h=10,$fn=30,center=true);
        translate([0,0,0]) cube([4,7,10],true);
    }
}


module tripod()
{
    rotate([90,0,0]) {
        cylinder(h=10,d=9,center=true);
        translate([0,8,0]) cylinder(h=10,d=3,$fn=30,center=true);
        rotate([0,0,120]) translate([0,8,0]) cylinder(h=10,d=3,$fn=30,center=true);
        rotate([0,0,-120]) translate([0,8,0]) cylinder(h=10,d=3,$fn=30,center=true);
    }
}

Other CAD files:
openSCAD/detector2.stl
FreeCAD/LCD_spacer.stl
FreeCAD/receiver_box.stl
FreeCAD/receiver_lid.stl
FreeCAD/remote_box.stl
FreeCAD/remote_eye.stl
FreeCAD/remote_lid.stl
FreeCAD/sun_shield.stl

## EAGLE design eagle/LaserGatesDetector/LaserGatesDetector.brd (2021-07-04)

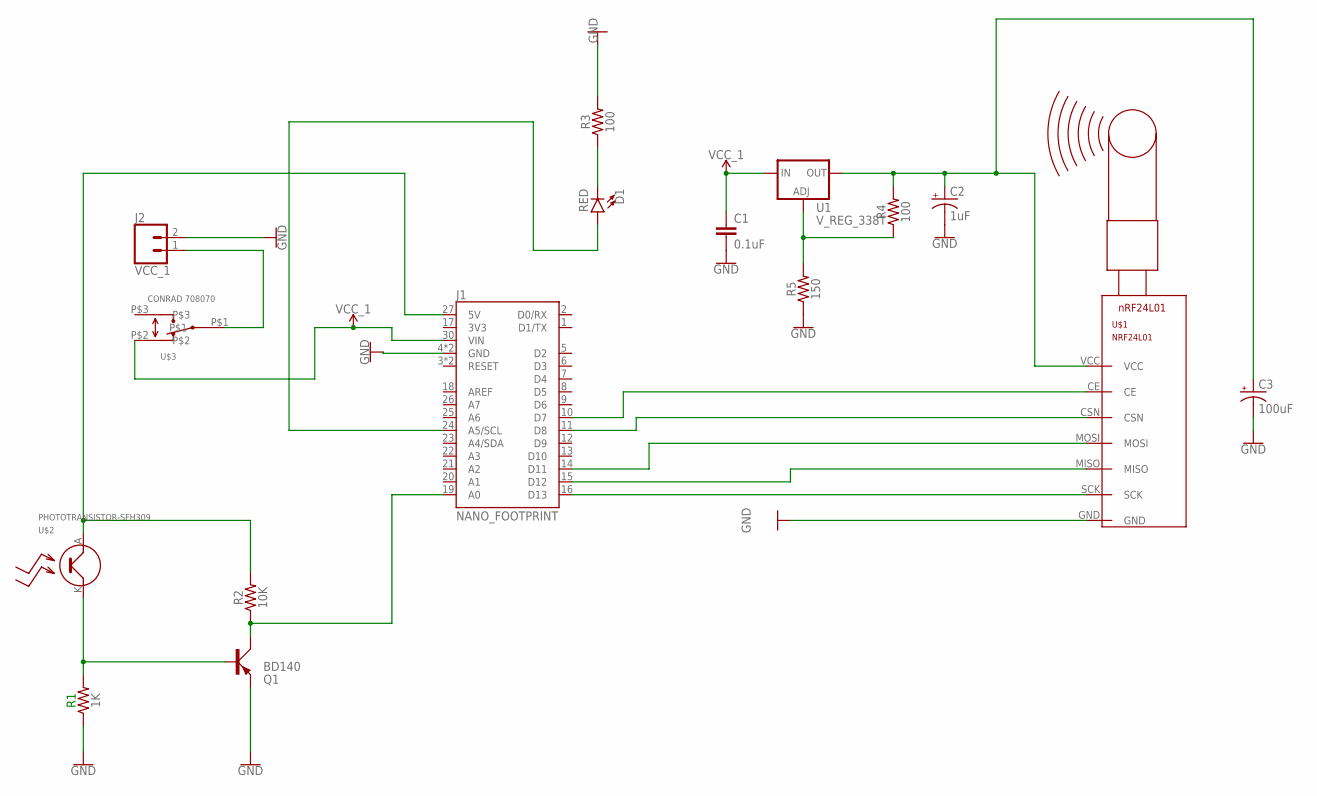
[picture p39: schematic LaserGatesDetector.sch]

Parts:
C1: 0.1uF; CAP-PTH-SMALL-KIT
C2: 1uF; CPOL-RADIAL-2.5MM-5MM
C3: 100uF; CPOL-RADIAL-5MM-10MM
D1: RED; LED_5MM-KIT
J1: NANO_FOOTPRINT; NANO
J2: VCC_1; 1X02
Q1: BD140; TO126AV
R1: 1K; AXIAL-0.3
R2: 10K; AXIAL-0.3
R3, R4: 100; AXIAL-0.3
R5: 150; AXIAL-0.3
U1: V_REG_338T; TO220-ADJ
U$1: NRF24L01
U$2: PHOTOTRANSISTOR-SFH309; SFH
U$3: SLIDE-SWITCH-CONRAD708070

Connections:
GND: C1.2, C2.2 (-), C3.-, J1.4 (GND), J1.29 (GND), J2.2, Q1.E, R1.P$1 (1), R3.P$2 (2), R5.P$1 (1), U$1.GND
unnamed: J1.11 (D8), U$1.CSN
unnamed: J1.10 (D7), U$1.CE
unnamed: J1.16 (D13), U$1.SCK
unnamed: J1.14 (D11), U$1.MOSI
unnamed: J1.15 (D12), U$1.MISO
unnamed: Q1.B, R1.P$2 (2), U$2.K
unnamed: D1.A, J1.24 (A5/SCL)
unnamed: D1.K (C), R3.P$1 (1)
unnamed: J2.1, U$3.P$1
unnamed: J1.27 (5V), R2.P$2 (2), U$2.A
unnamed: J1.19 (A0), Q1.C, R2.P$1 (1)
unnamed: R4.P$1 (1), R5.P$2 (2), U1.ADJ
unnamed: C2.1 (+), C3.+, R4.P$2 (2), U1.OUT, U$1.VCC
VCC_1: C1.1, J1.30 (VIN), U1.IN, U$3.P$2

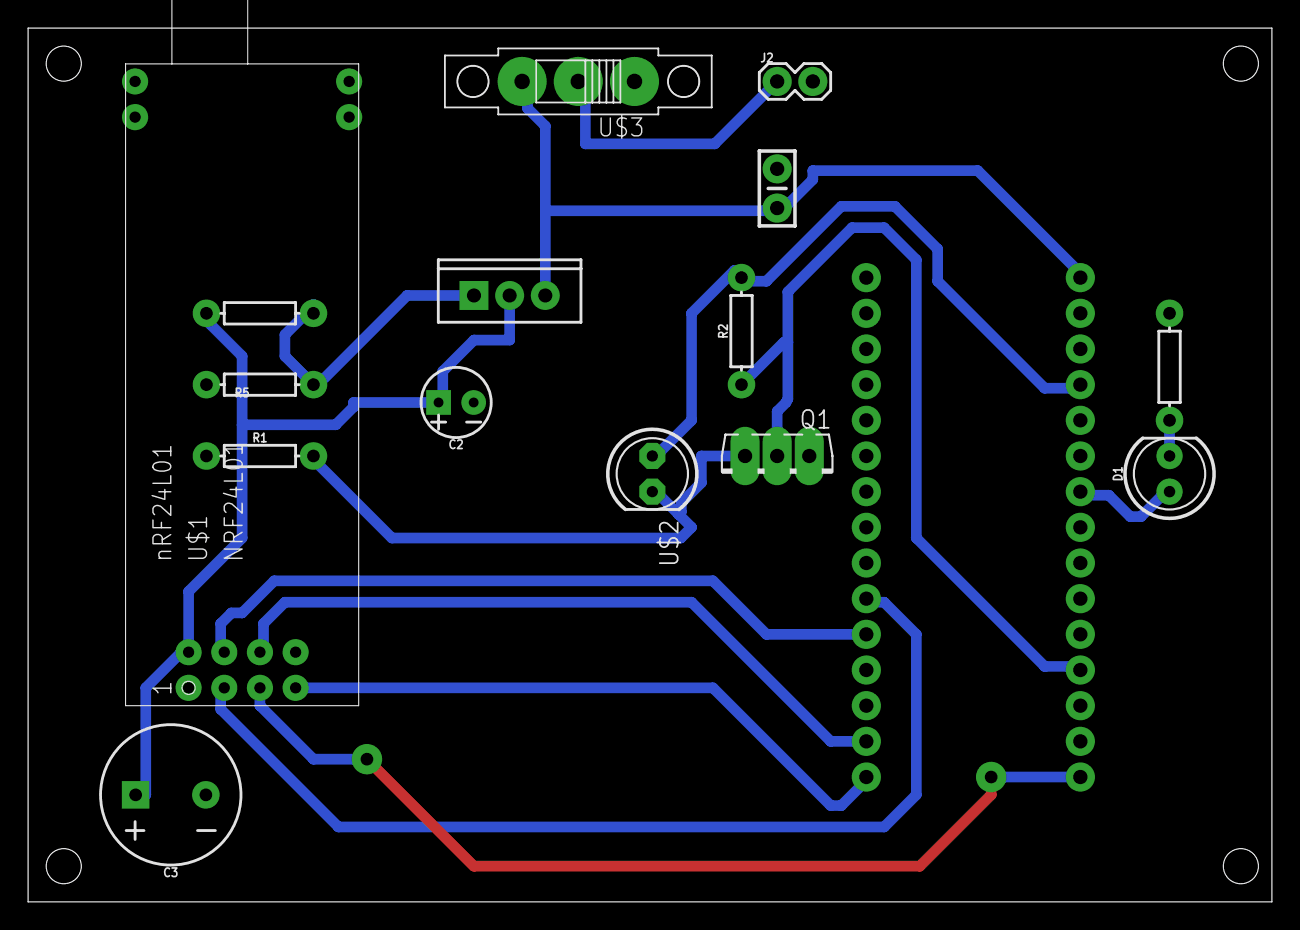
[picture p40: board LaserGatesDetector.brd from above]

Board: 2 copper layers, 88.6 x 62.2 mm, 16 parts (0 on the bottom side), 15 nets.

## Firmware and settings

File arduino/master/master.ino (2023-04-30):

// MultiTxAckPayload - the master or the transmitter
//   works with two Arduinos as slaves
//     each slave should the SimpleRxAckPayload program
//       one with the adress {'R','x','A','A','A'}
//         and the other with {'R','x','A','A','B'}

#include <SPI.h>
#include <nRF24L01.h>
#include <RF24.h>

#include <LiquidCrystal.h>
LiquidCrystal lcd(1,0,5,4,3,2);

#define CE_PIN   7
#define CSN_PIN 8

#define SERIAL false

const byte numSlaves = 2;
const byte slaveAddress[numSlaves][5] = {
        // each slave needs a different address
                            {'R','x','A','A','A'},
                            {'R','x','A','A','B'}
                        };

RF24 radio(CE_PIN, CSN_PIN); // Create a Radio

//~ char dataToSend[10] = "Message 0";
char dataToSend[32] = "ToSlvN  0";
char txNum = '0';
long int ackData[3] = {-1, -1,-1}; // to hold the two values coming from the slave
bool newData = false;
bool gates_closed;

unsigned long currentMillis;
unsigned long prevMillis;
unsigned long txIntervalMillis = 1000; // send once per second
unsigned long timer_sync[2],time_slaves[2]; 
int valOld=LOW;
int reset1=LOW;

//===============

void setup() {
#if SERIAL
    Serial.begin(9600);
    Serial.println(F("Source File = /mnt/SGT/SGT-Prog/Arduino/ForumDemos/nRF24Tutorial/MultiTxAckPayload.ino "));
    Serial.println("SimpleTxAckPayload Starting");
#endif
#if !(SERIAL)
    lcd.begin(16,2);
#endif    
    pinMode(9,INPUT);

    radio.begin();
    radio.setChannel(120);
    //radio.setAutoAck(false);
    //radio.setPALevel(RF24_PA_MAX); // "short range setting" - increase if you want more range AND have a good power supply
    radio.setDataRate( RF24_1MBPS );

    radio.enableAckPayload();

    radio.setRetries(15,15); // delay, count

    
    currentMillis = millis();
    prevMillis=currentMillis;
}





//=============

void loop() {
    int val;
    bool gates_open;
    char test[2];
    currentMillis = millis();
    
    val=digitalRead(9);
    
    if((reset1==HIGH) ) {
        val=HIGH;
        valOld=LOW;
        reset1=LOW;
        delay(100);
    }
    /*dataToSend[0]='0';
    dataToSend[1]='2';
    test[0]=dataToSend[0];
    test[1]=dataToSend[1];
    Serial.println(atol(test));*/
    //if (currentMillis - prevMillis >= txIntervalMillis) {


    /* ************************************************************************/
    /* If system has just been reset (button pressed) *************************/
    /* ************************************************************************/
    if ((val==HIGH) && (valOld==LOW)) {
        sync_time_and_receive_gates_closed_status(&gates_closed);
        sync_time_and_receive_gates_closed_status(&gates_closed);
        delay(100);
        sync_time_and_receive_gates_closed_status(&gates_closed);
        sync_time_and_receive_gates_closed_status(&gates_closed);

#if SERIAL
        if(gates_closed) Serial.println("Ready");
        else Serial.println("Close gates");
#endif        
#if !(SERIAL)
        if(gates_closed) {
          lcd.clear();
          lcd.setCursor(0,0);
          lcd.print("Ready");
        }
        else {
          lcd.clear();
          lcd.setCursor(0,0);
          lcd.print("Close gates");
        }
#endif        

        delay(100);
    }
    valOld=val;
    /* ************************************************************************/
    /* end ********************************************************************/
    /* ************************************************************************/


    




    gates_open = !gates_closed;



    
    // poll until gates open
    if(gates_closed) {
      while(!gates_open) {
        val=digitalRead(9);
        if((val==HIGH) ) break;
  
  
        
        currentMillis = millis();
        if ((currentMillis - prevMillis) >= txIntervalMillis) {
          // poll
          poll_and_receive_time_and_gates_open_status(&gates_open);
#if SERIAL
          Serial.println("");
          Serial.println((int)gates_open);
#endif
          prevMillis=currentMillis;
        }
      }
      gates_closed=false;

      // calculate mm, ss, etc
//      unsigned long runMillis=abs(((long)time_slaves[1]-(long)timer_sync[1])-
//            ((long)time_slaves[0]-(long)timer_sync[0]));
      unsigned long runMillis=abs((long)time_slaves[1]-(long)time_slaves[0]+
            abs((long)timer_sync[1]-(long)timer_sync[0])); 
            // note, the difference between time_slaves[1] and [2] is less than actual time 
            // because the time_slaves[1] clock starts ticking after [0]
            // therefore add the offset on
      unsigned long allSeconds=runMillis/1000.;
      int runHours=allSeconds/3600;
      int secsRemaining=allSeconds%3600;
      int runMinutes=secsRemaining/60;
      int runSeconds=secsRemaining%60;
      int runMSeconds=runMillis%1000;
      char buf[21];
      sprintf(buf,"%02d:%02d:%03d",runMinutes,runSeconds,runMSeconds);

      
#if SERIAL
      if(val != HIGH) {
        Serial.println("The time was: ");
        Serial.println((long)time_slaves[1]-(long)time_slaves[0]);
      } else {
        Serial.println("Reset");
        reset1=HIGH;
        valOld=val;
      }
#endif      
#if !(SERIAL)
      if(val != HIGH) { // only if not due to button push
        lcd.clear();
        lcd.setCursor(0,0);
        lcd.print("The time was");
        lcd.setCursor(0,1);
        lcd.print(buf);
//        valOld=LOW;
      } else {
        lcd.clear();
        lcd.setCursor(0,0);
        lcd.print("Reset");
        reset1=HIGH;
        valOld=val;
      }
#endif      
    }    
    // now poll until gate


}

//================






void poll_and_receive_time_and_gates_open_status(bool *gates_open) {
    bool rslt;

        // call each slave in turn
    for (byte n = 0; n < numSlaves; n++){

            // open the writing pipe with the address of a slave
        radio.openWritingPipe(slaveAddress[n]);

        //timer_sync[n] = millis();
        sprintf(dataToSend,"%02d%ld",1,timer_sync[n]);
        rslt = radio.write( &dataToSend, sizeof(dataToSend) );
            // Always use sizeof() as it gives the size as the number of bytes.
            // For example if dataToSend was an int sizeof() would correctly return 2

#if SERIAL
        Serial.print("  ========  For Slave ");
        Serial.print(n);
        Serial.println("  ========");
        Serial.print("  Data Sent ");
        Serial.print(dataToSend);
#endif        
        if (rslt) {
            if ( radio.isAckPayloadAvailable() ) {
                radio.read(&ackData, sizeof(ackData));
                time_slaves[n]=ackData[2]; // this is how long each gate was closed for
                newData = true;
                if(n==0) *gates_open=!(bool)ackData[0];
                else *gates_open *=!(bool)ackData[0];
            }
            else {
#if SERIAL
                Serial.println("  Acknowledge but no data ");
#endif
                *gates_open=false;
            }
            updateMessage();
        }
        else {
#if SERIAL
            Serial.println("  Tx failed");
#endif            
            *gates_open=false;
        }
        showData(n);
#if SERIAL
        Serial.print("\n");
#endif        
    }

 }


//=================

void sync_time_and_receive_gates_closed_status(bool *gates_closed) {
    bool rslt;
  
        // call each slave in turn
    for (byte n = 0; n < numSlaves; n++){

            // open the writing pipe with the address of a slave
        radio.openWritingPipe(slaveAddress[n]);

            // include the slave number in the message
        dataToSend[5] = n + '0';
        timer_sync[n] = millis();
        sprintf(dataToSend,"%02d%ld",0,timer_sync[n]);
        // Write the timer sync (current time) to the slave (i.e. the detector)
        rslt = radio.write( &dataToSend, sizeof(dataToSend) );
            // Always use sizeof() as it gives the size as the number of bytes.
            // For example if dataToSend was an int sizeof() would correctly return 2

#if SERIAL
        Serial.print("  ========  For Slave ");
        Serial.print(n);
        Serial.println("  ========");
        Serial.print("  Data Sent ");
        //Serial.print(rslt);
        Serial.print(dataToSend);
#endif        
        // receive a message back from the slave
        if (rslt) {
            if ( radio.isAckPayloadAvailable() ) {
                //timer_sync[n] = millis();
                radio.read(&ackData, sizeof(ackData));
                newData = true;
#if SERIAL
                Serial.println("Here");
                Serial.println(ackData[0]);
#endif
                if(n==0) *gates_closed=(bool)ackData[0];
                else *gates_closed *=(bool)ackData[0];
                //timer_sync[n] = millis();
            }
            else {
#if SERIAL
                Serial.println("  Acknowledge but no data ");
#endif                
                *gates_closed=false;
            }
            updateMessage();
        }
        else {
#if SERIAL
            Serial.println("  Tx failed");
#endif            
            *gates_closed=false;
        }
        showData(n);
#if SERIAL
        Serial.print("\n");
#endif        
    }

 }


//=================

void showData(byte n) {
    if (newData == true) {
#if SERIAL
        Serial.print("  Acknowledge data ");
        Serial.print(ackData[0]);
        Serial.print(", ");
        Serial.print(ackData[1]);
        Serial.print(", ");
        Serial.println(ackData[2]);
        Serial.println();
#else
        // n is the slave
        if(n==0) {
          //lcd.clear();
          lcd.setCursor(0,0);
          lcd.print("Gate 0 comm OK");
        } else if (n==1) {
          lcd.setCursor(0,1);
          lcd.print("Gate 1 comm OK");
        }

#endif        
        newData = false;
    }
}

//================

void updateMessage() {
        // so you can see that new data is being sent
    txNum += 1;
    if (txNum > '9') {
        txNum = '0';
    }
    dataToSend[8] = txNum;
}

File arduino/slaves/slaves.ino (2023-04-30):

// SimpleRxAckPayload- the slave or the receiver
#include <avr/wdt.h>

#include <SPI.h>
#include <nRF24L01.h>
#include <RF24.h>

#define CE_PIN   7
#define CSN_PIN 8

#define SERIAL false

#define GATE 0
#if GATE==0
const byte thisSlaveAddress[5] = {'R','x','A','A','A'};
#endif
#if GATE==1
const byte thisSlaveAddress[5] = {'R','x','A','A','B'};
#endif

RF24 radio(CE_PIN, CSN_PIN);

char dataReceived[32]; // this must match dataToSend in the TX
long int ackData[3] = {109, -4000, -10000}; // the two values to be sent to the master
bool newData = false;
bool gate_flag, gate_flag_old=true;
unsigned long timer_sync,gate_open_timer,timer_local_sync;
long message_code;
bool reset_flag=false;
//==============



void setup() {

    pinMode(2,OUTPUT);
    digitalWrite(2,HIGH);
#if SERIAL
    Serial.begin(9600);

    Serial.println("SimpleRxAckPayload Starting");
#endif

    radio.begin();
    radio.setChannel(120);
    //radio.setAutoAck(false);
    //radio.setPALevel(RF24_PA_MAX); // "short range setting" - increase if you want more range AND have a good power supply
    radio.setDataRate( RF24_1MBPS );

    radio.openReadingPipe(1, thisSlaveAddress);

    radio.enableAckPayload();
    radio.writeAckPayload(1, &ackData, sizeof(ackData)); // pre-load data

    radio.startListening();
    //reset1();
}

//==========

void loop() {

    // read photo-diode signal
    int val=analogRead(A7);
    // 950 worked for a long time in summmer / autumn
    gate_flag=(val >= 750) ? true : false;

    // set LED value to high if laser is detected, low if not
    if(gate_flag) { 
      digitalWrite(2,HIGH);
    }
    else {
      digitalWrite(2,LOW);
    }


    if(gate_flag==false && gate_flag_old==true && reset_flag==true) {
      gate_open_timer=millis();
      reset_flag=false;
    }
    //Serial.println(reset_flag);

    
    getData();
    showData();
    gate_flag_old=gate_flag;
}

//============

void getData() {
    char str1[2];
    unsigned long test = millis();
    if ( radio.available() ) {
        
        radio.read( &dataReceived, sizeof(dataReceived) );
        str1[0]=dataReceived[0];
        str1[1]=dataReceived[1];
        
        message_code=atol(str1);
        if(message_code==0) {
          timer_local_sync=test; // this is when the sync signal is received on the slave
#if SERIAL
          Serial.println(message_code);
#endif
          timer_sync=atol(&dataReceived[2]);
          reset_flag=true;
#if SERIAL          
          Serial.println(dataReceived);
#endif
        } else if(message_code==1) {
          // send the time the gate was opened 
          
        }
        updateReplyData();
        newData = true;
    }
}

//================

void showData() {
    if (newData == true) {
#if SERIAL      
        Serial.print("Data received ");
        Serial.println(dataReceived);
        Serial.print(" ackPayload sent ");
        Serial.print(ackData[0]);
        Serial.print(", ");
        Serial.println(ackData[1]);
#endif        
        newData = false;
    }
}

//================

void updateReplyData() {
    ackData[0] -= 1;
    ackData[1] -= 1;
    if (ackData[0] < 100) {
        ackData[0] = 109;
    }
    if (ackData[1] < -4009) {
        ackData[1] = -4000;
    }
    ackData[0]=((long)gate_flag)*((long)reset_flag);
    ackData[1]=(long)timer_sync;
    ackData[2]=(long)gate_open_timer-(long)timer_local_sync;  // this is how long gate was closed for
    radio.writeAckPayload(1, &ackData, sizeof(ackData)); // load the payload for the next time
}

void reset1()
{
  // enable the watchdog timer. This will wake up the board after 120ms
  wdt_enable(WDTO_120MS);
  
  // go to deep sleep
  if (true)
  {
    SMCR |= (1 << 2); // power down mode
    SMCR |= 1;        // enable sleep;
    __asm__ __volatile__("sleep");
  }    
}

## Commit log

2021-07-04 added PCB board designs, improved laser enclosure box for charging, etc
    [LaserGatesController.brd, LaserGatesController.sch, LaserGatesDetector.brd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]
2023-04-30 updates and bug fixes
    [LCD_spacer.FCStd, LCD_spacer.stl, receiver_box.FCStd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]

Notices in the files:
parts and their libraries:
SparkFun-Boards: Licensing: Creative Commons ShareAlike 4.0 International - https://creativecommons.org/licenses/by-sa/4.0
